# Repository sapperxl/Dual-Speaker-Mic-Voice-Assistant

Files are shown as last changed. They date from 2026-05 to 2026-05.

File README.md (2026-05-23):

I tried out a few of the voice assistant designs on Makerworld and tried the ESP32-S3-Box3 and I found all of them to be lacking either in the mic or speaker output so I came up with this design. This utilizes 2 10W 2” full range speakers and 2 INMP441 microphones. This mofo is pretty loud, not great bass, but definitely loud. The ESP32-S3 I use also includes an external antenna which I find greatly increases wifi signal. The grille on this assistant is a separate items so I could give some customization for the different ones throughout the house. More grille models coming. 

BOM:  
1ea 3a+ 12V Power Supply, combined speaker output is up to 20W so you will need at least a 3a power supply 5a is better.  https://www.amazon.com/dp/B0BTYSS82L  
1ea 12V input jack that matches the power supply barrel & pin dimensions  https://www.amazon.com/dp/B07CTCLKPP  
1ea PCM5102 I2S IIS Lossless Digital Audio DAC  https://www.amazon.com/dp/B08YNJGSN4  
1ea PAM8610 2x15W Digital Dual Channel Stereo Audio Amplifier Board    https://www.amazon.com/dp/B00WSN9S4Q  
1ea ESP32-S3 Development Board 16MB Flash/8MB PSRAM /w IPEX External Antenna  https://www.amazon.com/dp/B0FS16VYZ7  
1ea 12V to 5V Regulator Buck Converter  https://www.amazon.com/dp/B08JZ5FVLC  
2ea INMP441 Mics  https://www.amazon.com/dp/B0C1C64R8S  
2ea 2" 10W Full Range Speakers  https://www.amazon.com/dp/B0CCP2Q168  
4 Key 1x4 Keyboard Module https://www.amazon.com/dp/B0FGXKM3QD
2ea 10K 1/4watt metal film resistors 

Keep in mind the 3.5mm output from the PCM5102 is for a line level load, it will not drive headphones but works great with an external self-powered speaker.

On the PCM5102s I got from Amazon none of the solder pads were soldered so I wasn’t getting any output initially, it should look like this:


Thanks to A. Pauna on Amazon for their review of the PCM5102 that included a schematic and Carey Brown on Amazon that pointed out the PCM5102 solder pad issue on a review. Also 3DMN https://makerworld.com/en/@3DMN on Makerworld for their voice assistant design that inspired some of this one.

PCM5102 Module


PAM8610 Module


Buck Converter


ESP32



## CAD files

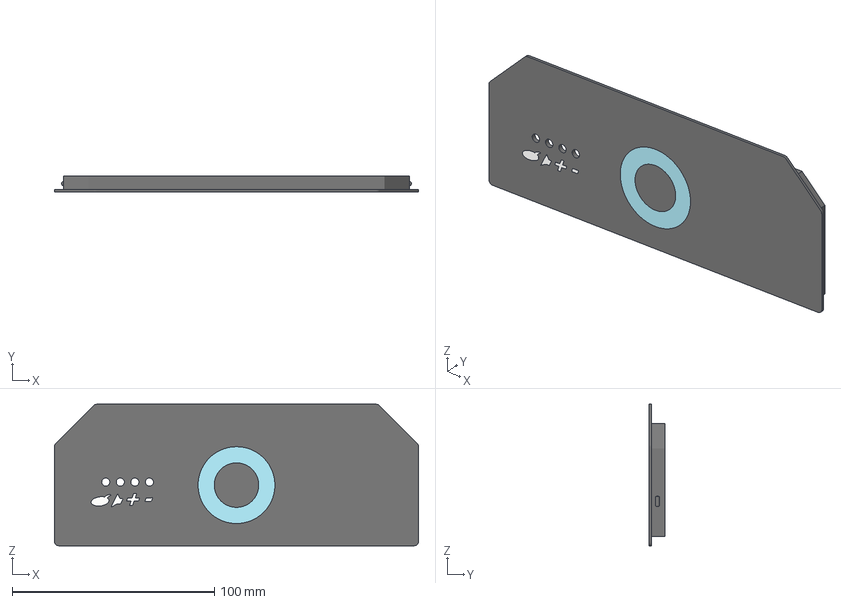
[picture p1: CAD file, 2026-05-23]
3dModels/Voice Assistant Lid (Assembly).3mf
180.0 x 8.04 x 70.0 mm

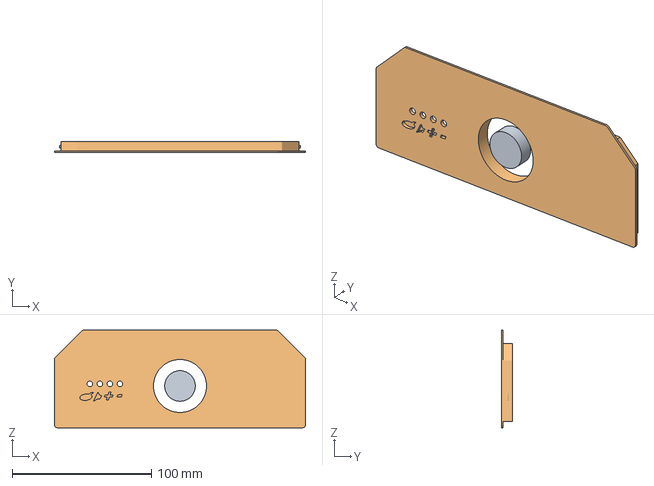
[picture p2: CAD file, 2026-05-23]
3dModels/Voice Assistant Lid.3mf
180.0 x 8.00 x 70.0 mm

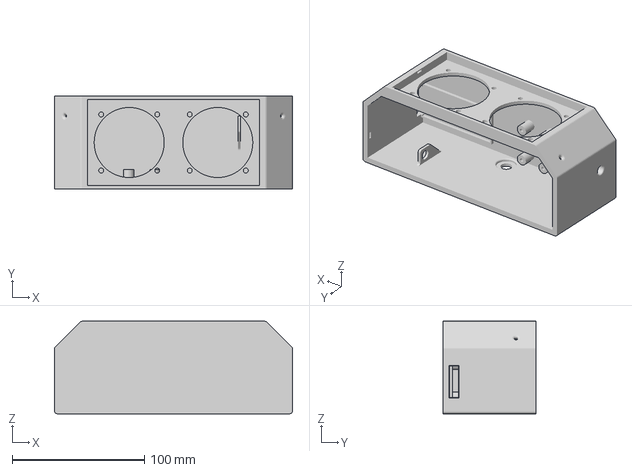
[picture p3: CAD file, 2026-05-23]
3dModels/Voice Assistant Chassis.3mf
180.0 x 70.0 x 70.0 mm

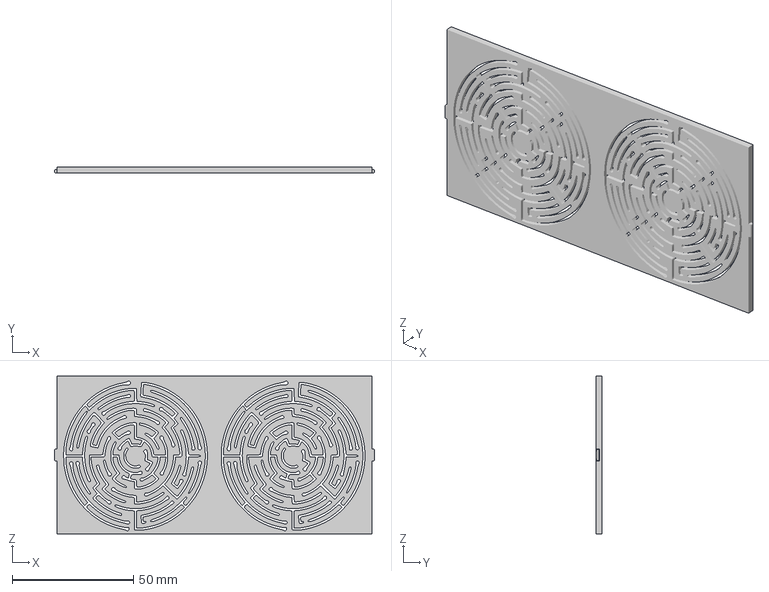
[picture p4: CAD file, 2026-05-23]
3dModels/Voice Assistant Grille.3mf
132.0 x 2.40 x 65.0 mm

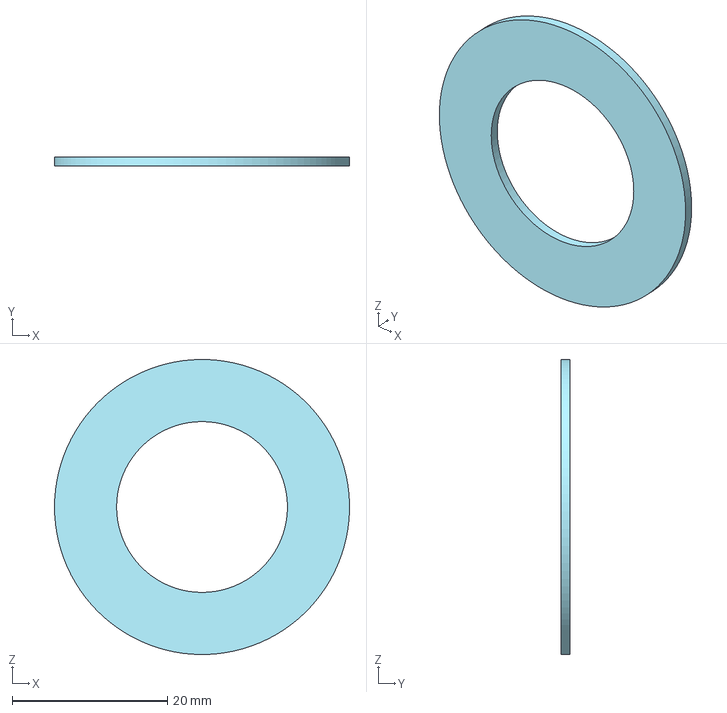
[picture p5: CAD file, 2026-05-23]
3dModels/Diffuser Ring.3mf
38.0 x 1.20 x 38.0 mm

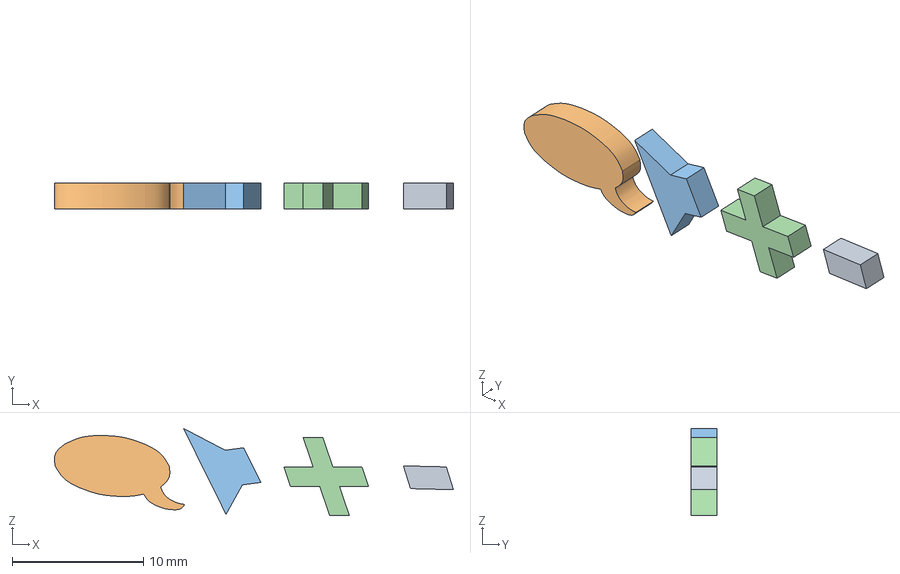
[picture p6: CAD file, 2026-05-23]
3dModels/Button Labels.3mf
30.4 x 2.00 x 6.65 mm

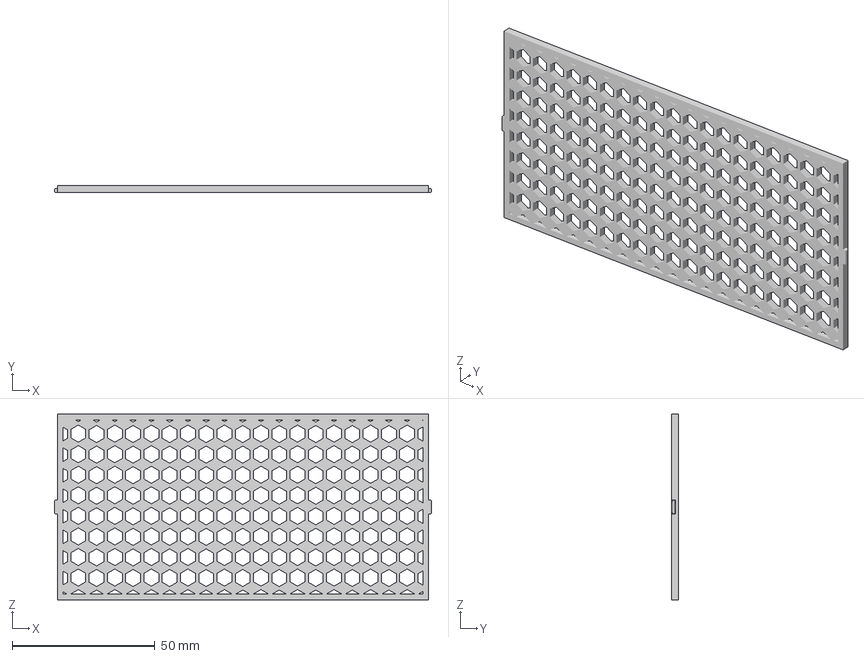
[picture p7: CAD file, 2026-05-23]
3dModels/Voice Assistant Grille Honeycomb.3mf
132.0 x 2.40 x 65.0 mm

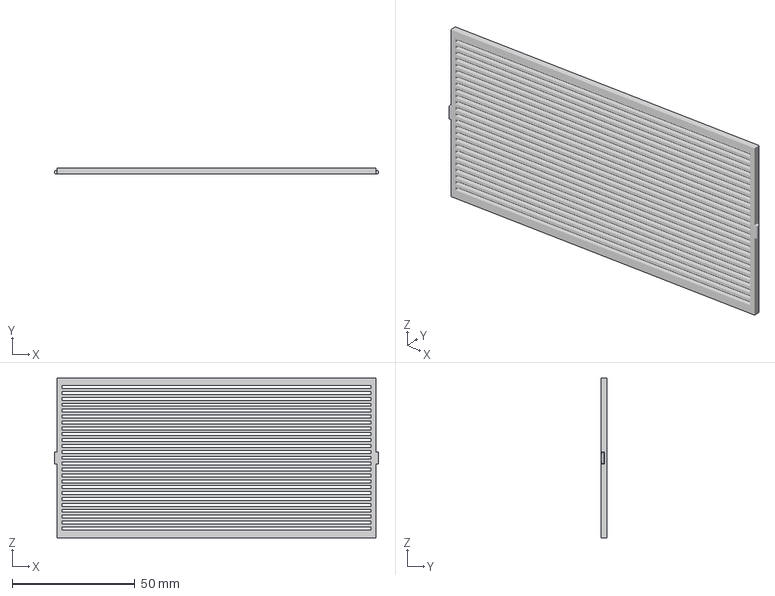
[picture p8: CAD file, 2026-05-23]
3dModels/Voice Assistant Grille Horizontal Slots.3mf
132.0 x 2.40 x 65.0 mm

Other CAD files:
3dModels/Voice Assistant Grille Round Circuits.3mf

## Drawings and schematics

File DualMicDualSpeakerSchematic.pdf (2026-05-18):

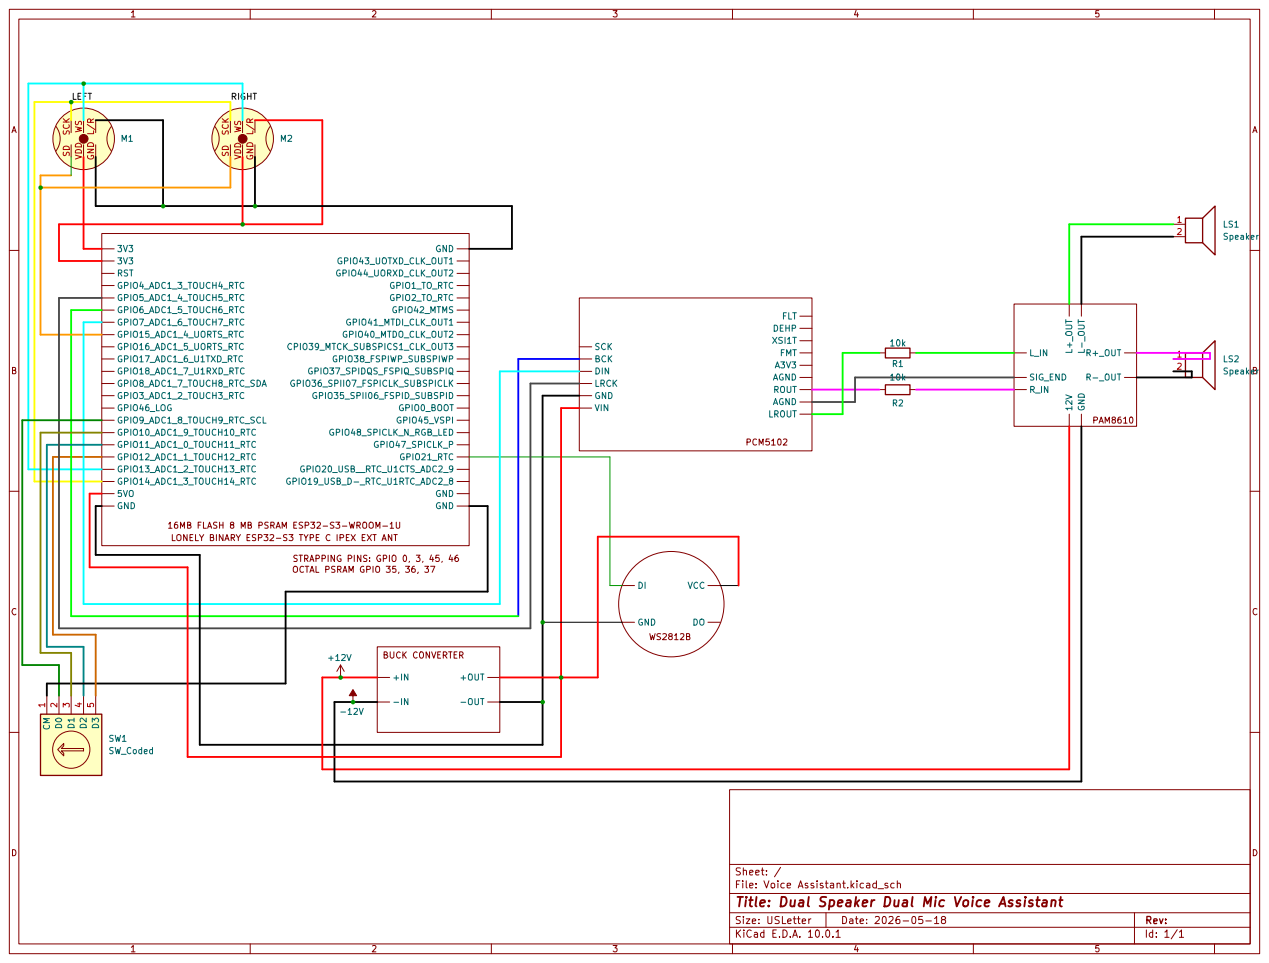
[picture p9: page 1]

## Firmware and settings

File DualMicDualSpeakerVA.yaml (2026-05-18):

substitutions:
  # Phases of the Voice Assistant
  # The voice assistant is ready to be triggered by a wake word
  voice_assist_idle_phase_id: '1'
  # The voice assistant is waiting for a voice command (after being triggered by the wake word)
  voice_assist_waiting_for_command_phase_id: '2'
  # The voice assistant is listening for a voice command
  voice_assist_listening_for_command_phase_id: '3'
  # The voice assistant is currently processing the command
  voice_assist_thinking_phase_id: '4'
  # The voice assistant is replying to the command
  voice_assist_replying_phase_id: '5'
  # The voice assistant is not ready
  voice_assist_not_ready_phase_id: '10'
  # The voice assistant encountered an error
  voice_assist_error_phase_id: '11'

esphome:
  name: home-assistant-voice
  friendly_name: Home Assistant Voice
  name_add_mac_suffix: true
  min_version: 2025.5.1
  on_boot:
    priority: 375
    then:
      # Run the script to refresh the LED status
      - script.execute: control_leds
      - delay: 1s
      - switch.turn_on: internal_speaker_amp
      - script.execute:
          id: play_sound
          priority: true
          sound_file: !lambda return id(wake_word_triggered_sound);
      # If after 10 minutes, the device is still initializing (It did not yet connect to Home Assistant), turn off the init_in_progress variable and run the script to refresh the LED status
      - delay: 10min
      - if:
          condition:
            lambda: return id(init_in_progress);
          then:
            - lambda: id(init_in_progress) = false;
            - script.execute: control_leds

esp32:
  board: esp32-s3-devkitc-1
  cpu_frequency: 240MHz
  variant: esp32s3
  flash_size: 16MB
  framework:
    type: esp-idf
    version: recommended
    sdkconfig_options:
      CONFIG_ESP32S3_DATA_CACHE_64KB: "y"
      CONFIG_ESP32S3_DATA_CACHE_LINE_64B: "y"
      CONFIG_ESP32S3_INSTRUCTION_CACHE_32KB: "y"

      # Moves instructions and read only data from flash into PSRAM on boot.
      # Both enabled allows instructions to execute while a flash operation is in progress without needing to be placed in IRAM.
      # Considerably speeds up mWW at the cost of using more PSRAM.
      CONFIG_SPIRAM_RODATA: "y"
      CONFIG_SPIRAM_FETCH_INSTRUCTIONS: "y"

      CONFIG_BT_ALLOCATION_FROM_SPIRAM_FIRST: "y"
      CONFIG_BT_BLE_DYNAMIC_ENV_MEMORY: "y"

      CONFIG_MBEDTLS_EXTERNAL_MEM_ALLOC: "y"
      CONFIG_MBEDTLS_SSL_PROTO_TLS1_3: "y"  # TLS1.3 support isn't enabled by default in IDF 5.1.5

wifi:
  id: wifi_id
  ssid: !secret wifi_ssid
  password: !secret wifi_password
  output_power: 15
  on_connect:
    - lambda: id(improv_ble_in_progress) = false;
    - script.execute: control_leds
  on_disconnect:
    - script.execute: control_leds

network:
  enable_ipv6: true

logger:
  level: DEBUG
  logs:
    sensor: WARN  # avoids logging debug sensor updates

api:
  id: api_id
  on_client_connected:
    - script.execute: control_leds
  on_client_disconnected:
    - script.execute: control_leds
  encryption:
    key: "fHStFI11FpMNpBXcy2DeLREtd8jvAsVe1Q6QaRcoxjY="

ota:
  - platform: esphome
    id: ota_esphome
    password: "7c7be216da0fccc1ea4e5a41d3b6153e"

psram:
  mode: octal
  speed: 80MHz


globals:
  # Global index for our LEDs. So that switching between different animation does not lead to unwanted effects.
  - id: global_led_animation_index
    type: int
    restore_value: no
    initial_value: '0'
  # Global initialization variable. Initialized to true and set to false once everything is connected. Only used to have a smooth "plugging" experience
  - id: init_in_progress
    type: bool
    restore_value: no
    initial_value: 'true'
  # Global variable storing the state of ImprovBLE. Used to draw different LED animations
  - id: improv_ble_in_progress
    type: bool
    restore_value: no
    initial_value: 'false'
  # Global variable tracking the phase of the voice assistant (defined above). Initialized to not_ready
  - id: voice_assistant_phase
    type: int
    restore_value: no
    initial_value: ${voice_assist_not_ready_phase_id}
  # Global variable tracking if the LED color was recently changed.
  - id: color_changed
    type: bool
    restore_value: no
    initial_value: 'false'
  # Global variable storing the first active timer
  - id: first_active_timer
    type: voice_assistant::Timer
    restore_value: false
  # Global variable storing if a timer is active
  - id: is_timer_active
    type: bool
    restore_value: false
  # Global variable storing if a factory reset was requested. If it is set to true, the device will factory reset once the center button is released
  - id: factory_reset_requested
    type: bool
    restore_value: no
    initial_value: 'false'
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
